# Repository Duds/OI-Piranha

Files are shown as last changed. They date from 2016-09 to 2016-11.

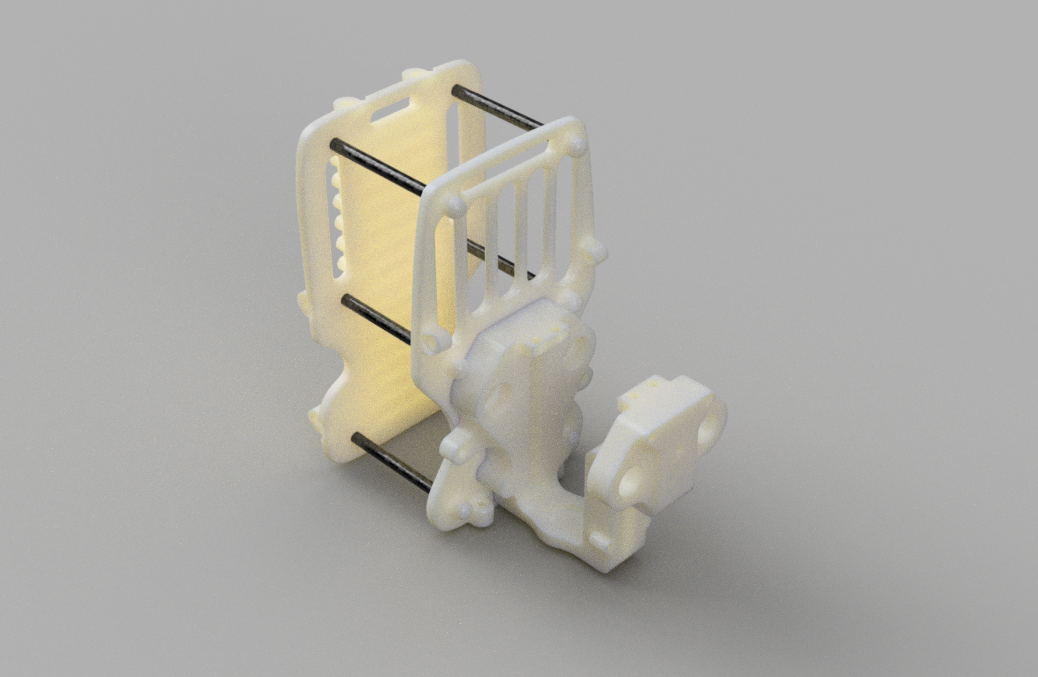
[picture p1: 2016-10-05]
200. Renders/Partial_Assembly_2016-Oct-04_11-32-55PM-000_CustomizedView4923803928.png

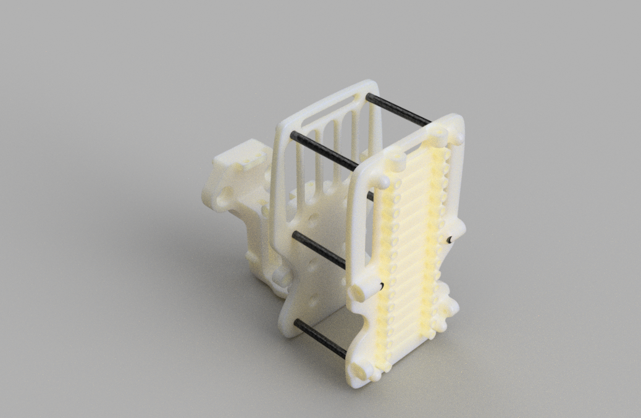
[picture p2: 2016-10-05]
200. Renders/Partial_Assembly_2016-Oct-04_11-32-44PM-000_CustomizedView13175151250.png

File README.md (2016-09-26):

# OI-Piranha
Open Inspired Piranha, an open source quadcopter design. Join the [Open Inspired community](http://openinspired.org) and get all the latest build tips, influence the design direction and start your own build log.

## Welcome to OI Piranha
I started OI Pirahna a bit by accident. I was trying to build the [DJI Inspired Version 1.5](http://www.rcgroups.com/forums/showthread.php?t=2399740) and the leadscrew I ordered arrived with a two start nut and a four start screw. I had some time to spare that I was planning to assemble my quad and so instead I sat down at my computer and wondered how hard it would be to design and print a four start nut for the leadscrew I had. As it happens 3d printing a four start nut won't work, the threads are too fine, for my printer anyway. So I designed a much larger leadscrew that would allow me to print a much larger nut. And then I thought this is silly, why am I copying a thread standard when I can design my own thread, with my own pitch and my own lead. Then, I thought hang on I don't even need a 360 degree continuos servo and top and bottom limit switches. All I need is a normal servo and I'll design the leadscrew to lift the body using the normal throw of the servo. Then I needed to know what the normal lift length was so I could design a leadscrew that would lift the body in 90 degrees. 

Many hours later, and I had roughly redesigned most of the aircraft frame. I had also viewed a stack of youtube videos on Fusion 360 design and learned a lot about top down design, the Fusion 360 timeline and a whole pile of stuff about 3d modelling.

When I was finished that first rough draft on my first night cram session I stood back and took a look at the frame and lift mechanism I had designed. I hadn't started on a fairing then. For some reason, the lump back where the battery goes and stubby little snout where the gimbal frame is reminded me of a fat stubby angry little predator fish. Not the lean fast fish like a tuna, but something maneuverable, still pretty fast, but much shorter and more agile. I went online to find out what kind of predator fish was short fat stubby and nasty. I found a photo of Piranha. I knew straight away that is what I had designed, a Piranha. And so I copied the photo of the pirahna in as a canvas and started work on my fairing.

## The Source
This design has been originally produced in Fusion 360. The original live source CAD file is at http://a360.co/2df5nqY

##Warning - Under Design
You are very welcome to make a fork of this design and to download the parts and print them. However, please be aware, this design is still a work in progress. Parts may not fit, or may break in use. Things may change and different versions of parts may not be compatible with versions of parts that you have printed. You might need to print things multiple times or find that parts fail during printing. All these challenges mean that, for now, the responsibility of starting and finishing an OI Piranha is not small. If you do take on the job your feedback is valued. Send your feedback good and bad to [Dale](mailto://hello@dalerogers.com.au)

##Credits
The Pirahna wouldn't exist if there weren't other DJI Inspired quadcopters before mine.
The first DJI Inspired was designed by [BlackBox RC](http://www.blackboxrc.co.uk/)
The BlackBox RC DJI Inspired was then modified, as the DJI Inspired v1.5 by Fragmaster on [RCGroups](http://www.rcgroups.com/forums/showthread.php?t=2399740)

Fragmaster was substantially supported during design by feedback and contributions from:
[Helifrek](http://www.rcgroups.com/forums/showthread.php?t=2330047),
[Mr.RCCAM](http://www.rc-cam.com/),
RTRyder,
[VladMiami](http://www.rcgroups.com/forums/showthread.php?t=2736573), and
many other contributors at [RCGroups](http://www.rcgroups.com/forums/showthread.php?t=2399740)

You can also find Thingiverse makes of the [BlackBox RC DJI Inspire](http://www.thingiverse.com/thing:593132) and, the [Fragmaster DJI Inspired V1.5](http://www.thingiverse.com/thing:909384)

I humbly apologise if you have contributed to the development of the DJI Inspired family of 3d printed quadcopters and you have not been mentioned. Please drop me an email at hello@dalerogers.com.au and I will correct the oversight. 

Those credited above have contributed to a great design, but all errors are mine.

Dale

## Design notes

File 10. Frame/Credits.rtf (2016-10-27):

These files were contributed by Whitedrag0n

Servo Caddy Top Mount.step
Servo Caddy Top Mount.iges
Servo Caddy Top Mount.stl

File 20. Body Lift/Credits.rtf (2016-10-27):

These files were contributed by Corwest

Lead Screw 9mm.step
Lead Screw 9mm.stl

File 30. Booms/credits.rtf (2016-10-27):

These files were contributed by Corwest

Boom Joint 16mm v1.1.step
Boom Joint 16mm v1.1.stl

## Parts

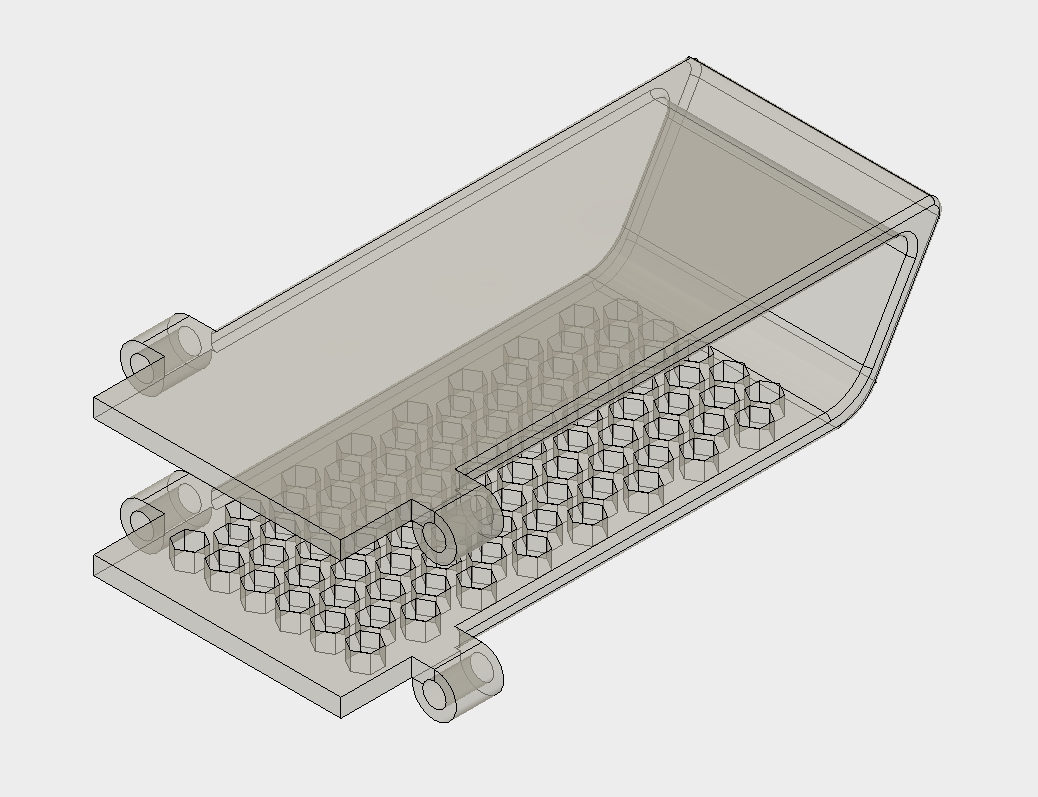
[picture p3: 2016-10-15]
40. Expansion Parts/DJI NAZA system expansion shelf.png

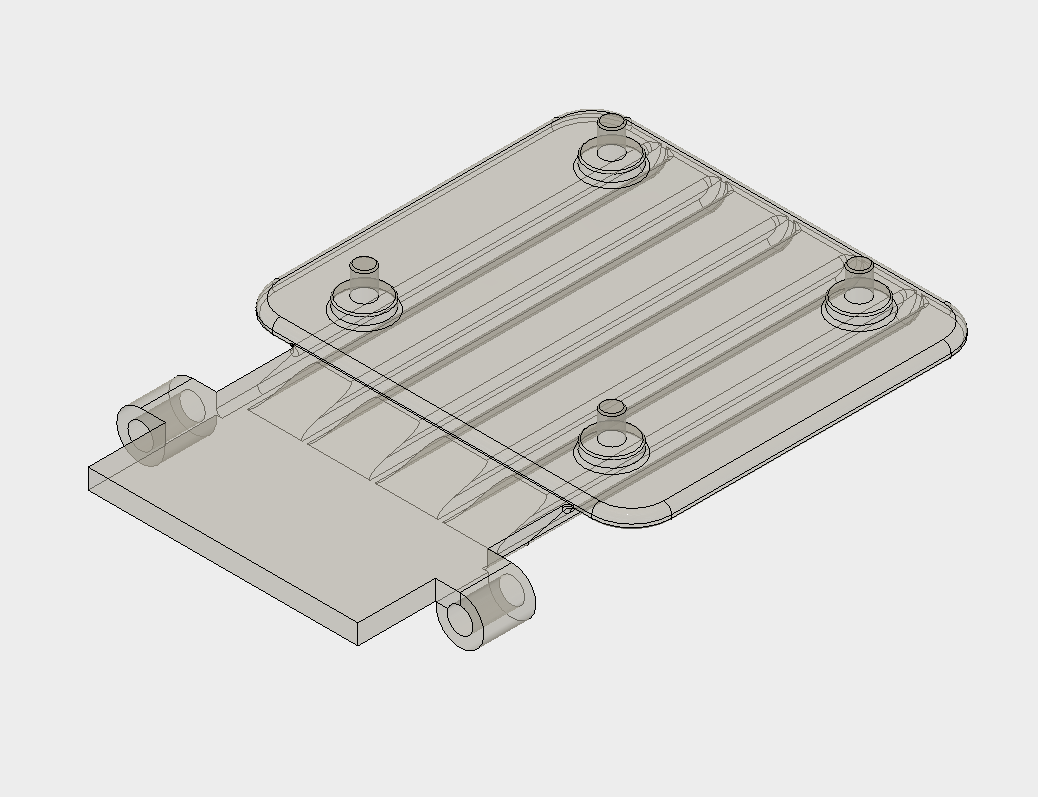
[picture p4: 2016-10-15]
40. Expansion Parts/NAZE32 expansion shelf.png

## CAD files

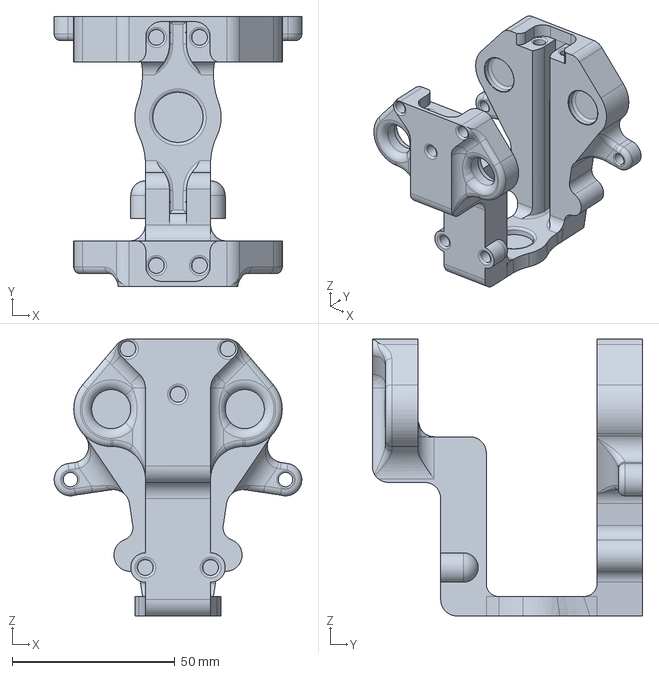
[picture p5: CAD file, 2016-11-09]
10. Frame/Main Frame.step
76.0 x 83.0 x 85.0 mm

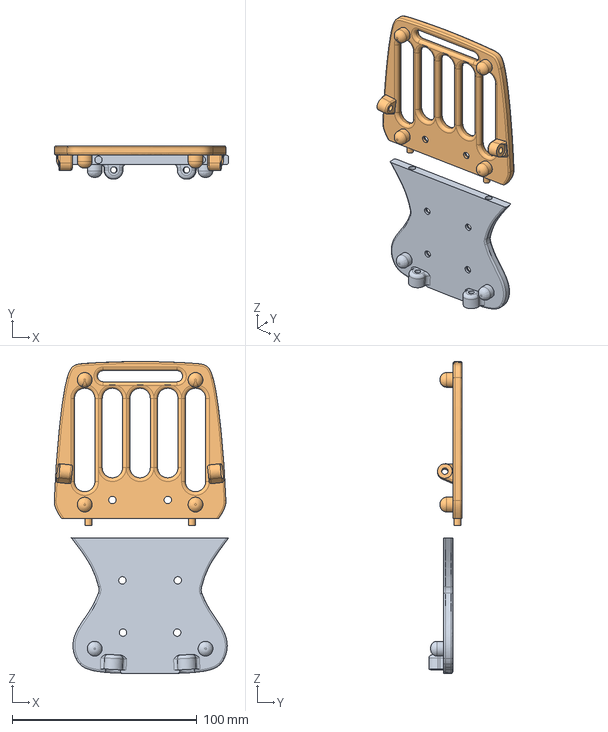
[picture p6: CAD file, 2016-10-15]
10. Frame/10.1 Two Part Frames (for smaller print volumes)/Battery Frame Two Part v1.step
94.5 x 18.1 x 168.9 mm
Battery Frame Part A
Battery Frame Part B

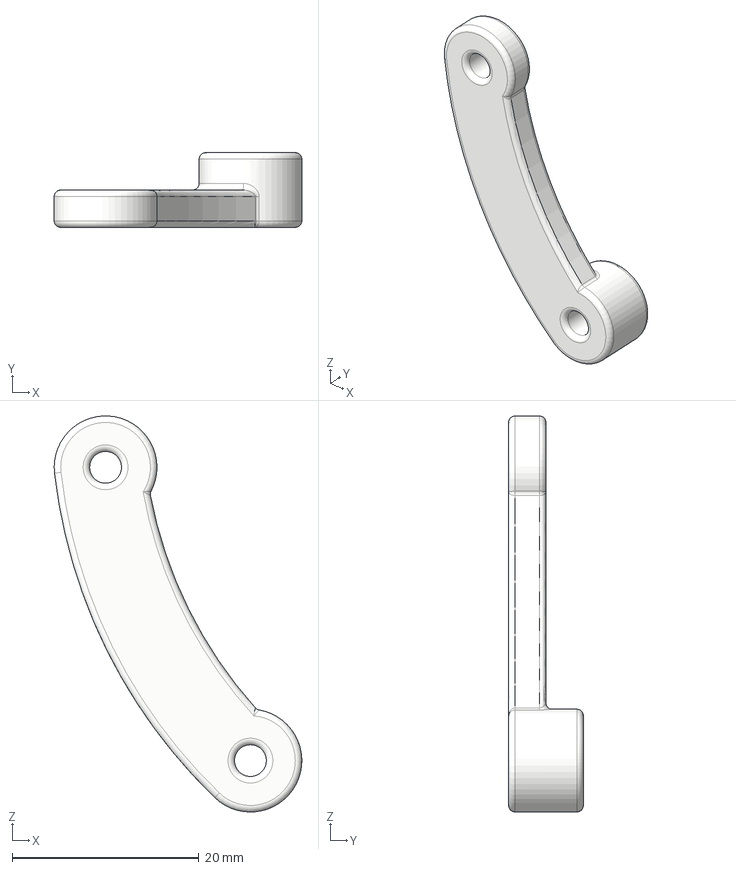
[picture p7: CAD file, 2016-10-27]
30. Booms/Lift linkage A.step
26.5 x 8.00 x 42.4 mm

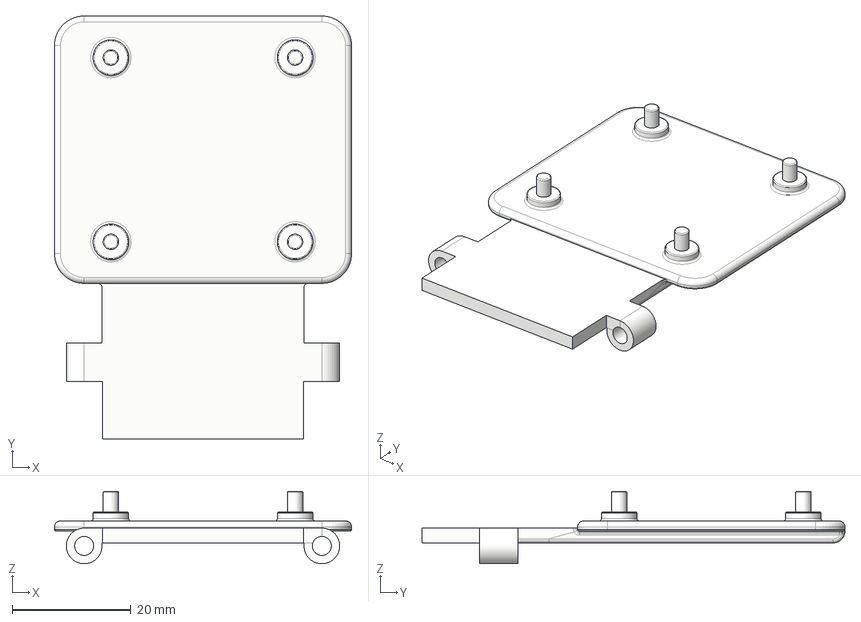
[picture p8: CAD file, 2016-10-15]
40. Expansion Parts/NAZE32 Expansion Shelf.step
50.0 x 71.2 x 12.2 mm

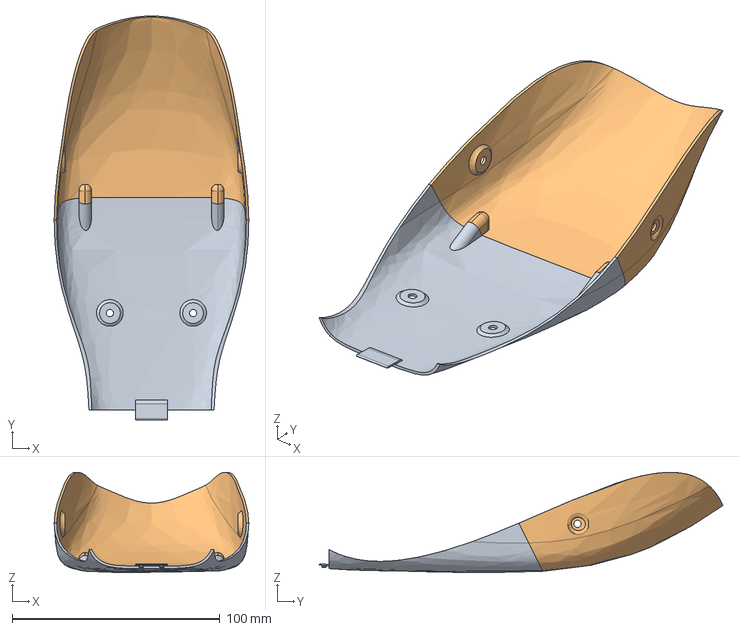
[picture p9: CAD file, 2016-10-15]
50. Fairings/50.1 two part fairing/Bash Plate Two Part.step
93.8 x 194.5 x 48.3 mm
Bash Plate part A
Bash Plate part B

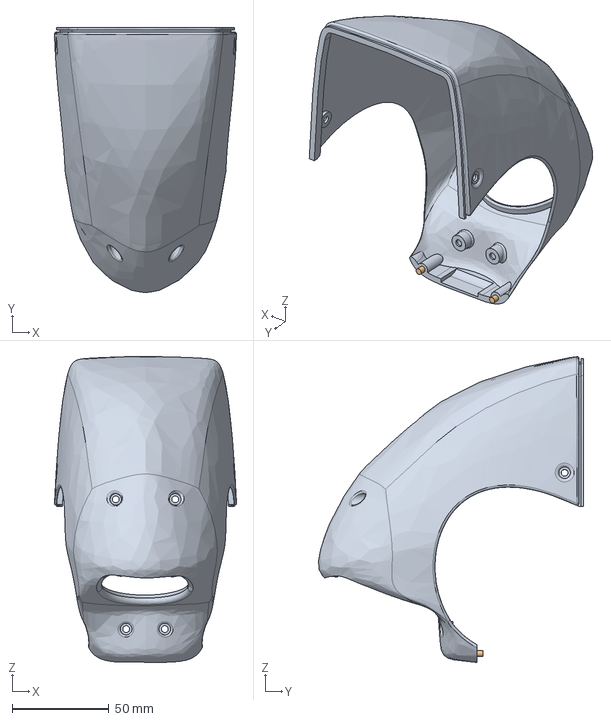
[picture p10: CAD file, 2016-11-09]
50. Fairings/Nose Fairing.step
94.2 x 137.1 x 158.3 mm

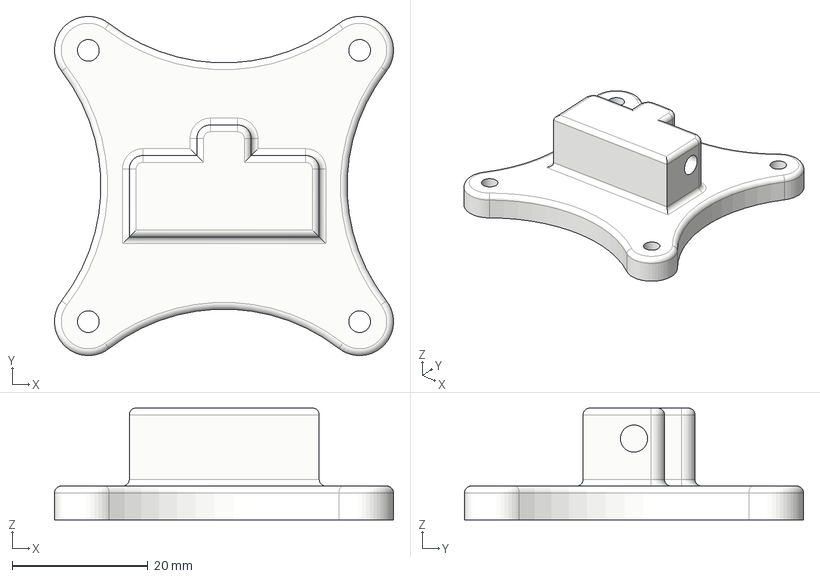
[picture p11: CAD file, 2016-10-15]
60. Payload/Gimbal Support.step
50.0 x 50.0 x 16.5 mm

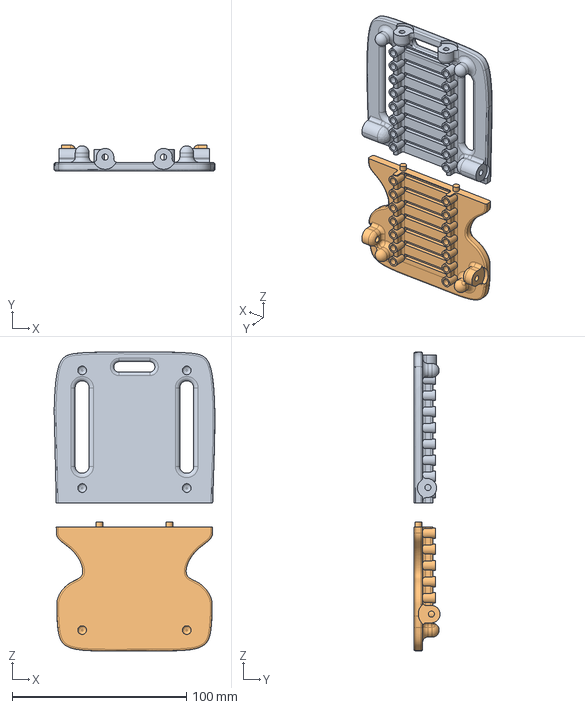
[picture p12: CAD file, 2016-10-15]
10. Frame/10.1 Two Part Frames (for smaller print volumes)/Expansion Frame Two Part.step
92.2 x 15.0 x 171.5 mm

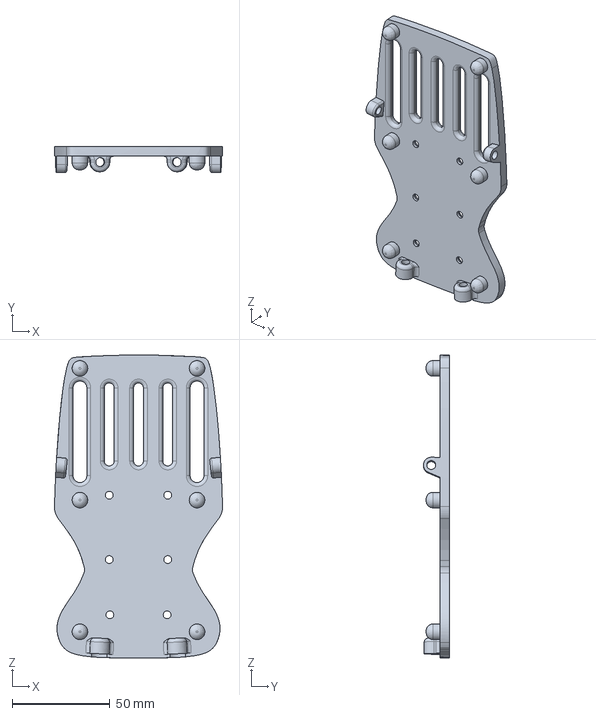
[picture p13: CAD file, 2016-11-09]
10. Frame/Battery Frame.step
86.2 x 13.4 x 155.3 mm

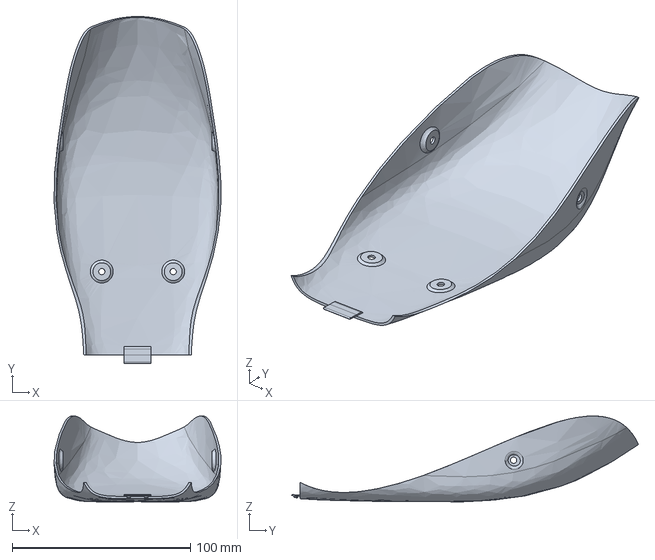
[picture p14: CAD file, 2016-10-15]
40. Expansion Parts/Bash Plate v12.step
93.6 x 194.5 x 48.2 mm

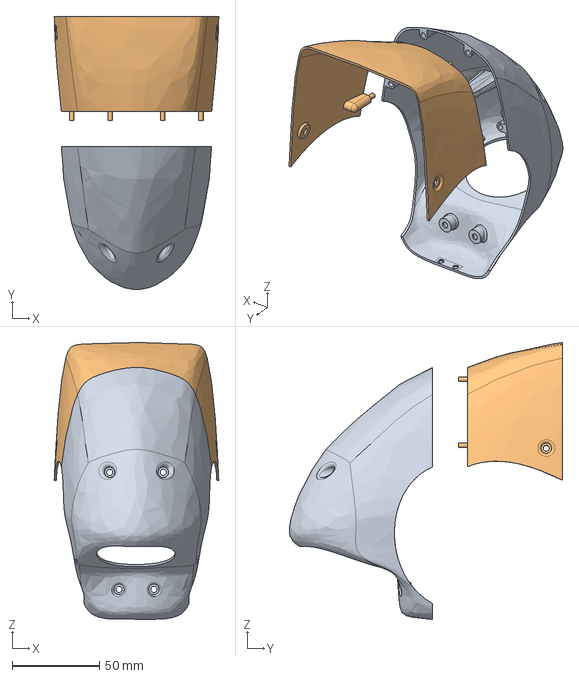
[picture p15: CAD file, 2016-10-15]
50. Fairings/50.1 two part fairing/Nose fairing two part.step
94.4 x 156.7 x 158.8 mm

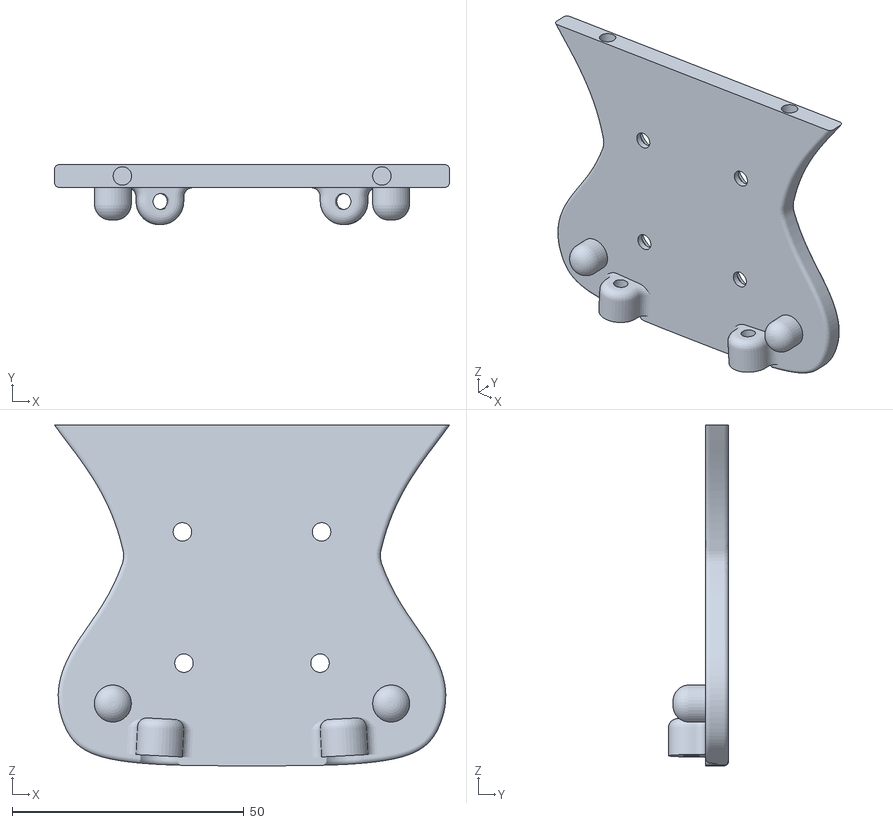
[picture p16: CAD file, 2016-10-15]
10. Frame/10.1 Two Part Frames (for smaller print volumes)/Battery Frame Part A.stl
85.1 x 13.0 x 73.4

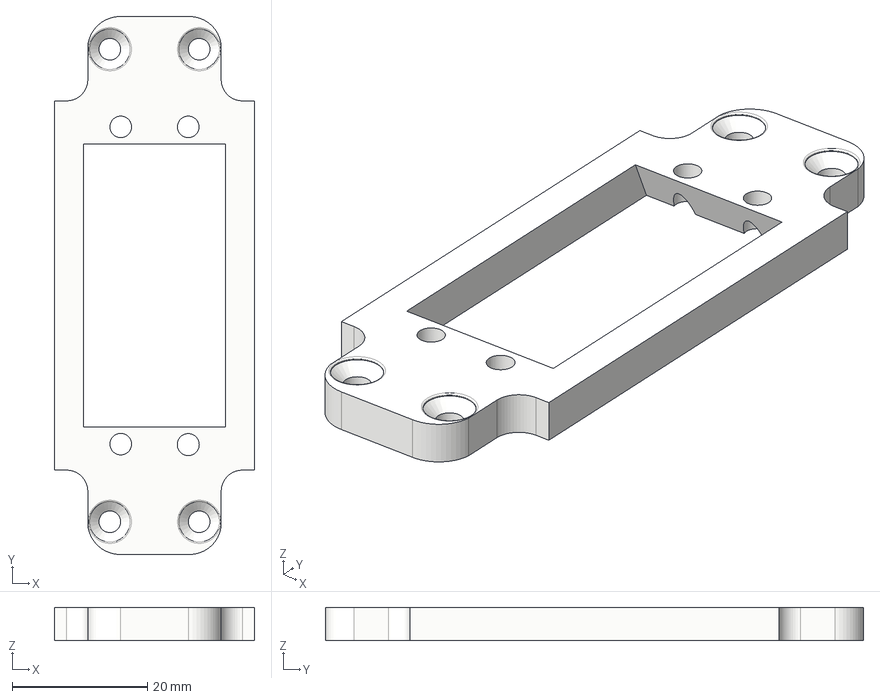
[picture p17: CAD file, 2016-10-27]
10. Frame/Servo Caddy.step
29.7 x 79.7 x 4.90 mm

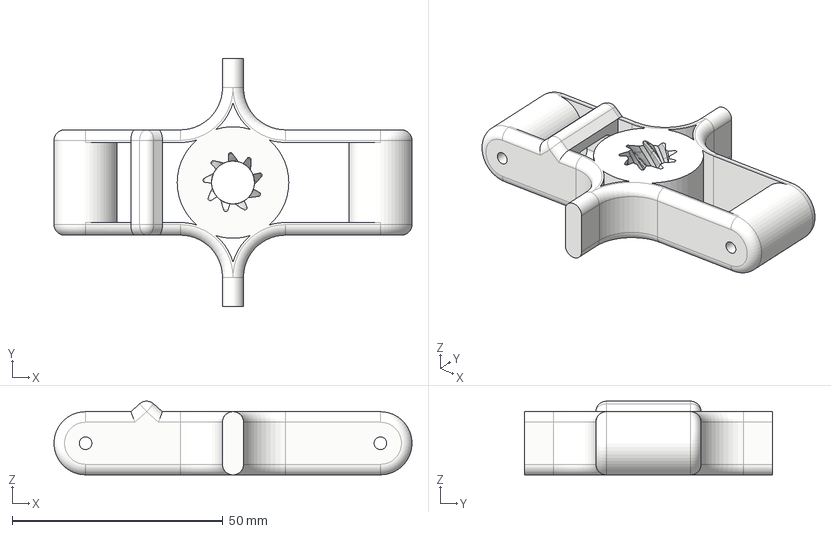
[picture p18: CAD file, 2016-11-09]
20. Body Lift/Lifting Beam (buttress thread).stp
85.0 x 58.8 x 17.5 mm

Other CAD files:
30. Booms/Lift Linkage B.step
50. Fairings/Bash Plate.step
30. Booms/Landing gear pivot.step
40. Expansion Parts/Basic Expansion Shelf.step
10. Frame/10.1 Two Part Frames (for smaller print volumes)/Battery Frame Part B.stl
10. Frame/10.1 Two Part Frames (for smaller print volumes)/Battery Frame Two Part v1.iges
10. Frame/10.1 Two Part Frames (for smaller print volumes)/Expansion Frame Two Part A.stl
10. Frame/10.1 Two Part Frames (for smaller print volumes)/Expansion Frame Two Part B.stl
10. Frame/10.1 Two Part Frames (for smaller print volumes)/Expansion Frame Two Part.iges
10. Frame/10.1 Two Part Frames (for smaller print volumes)/Lifting beam.step
10. Frame/Battery frame.iges
10. Frame/Battery frame.igs
10. Frame/Battery frame.stl
10. Frame/Expansion Frame.igs
10. Frame/Expansion Frame.step
10. Frame/Expansion frame.stl
10. Frame/Gimbal Support Frame.step
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

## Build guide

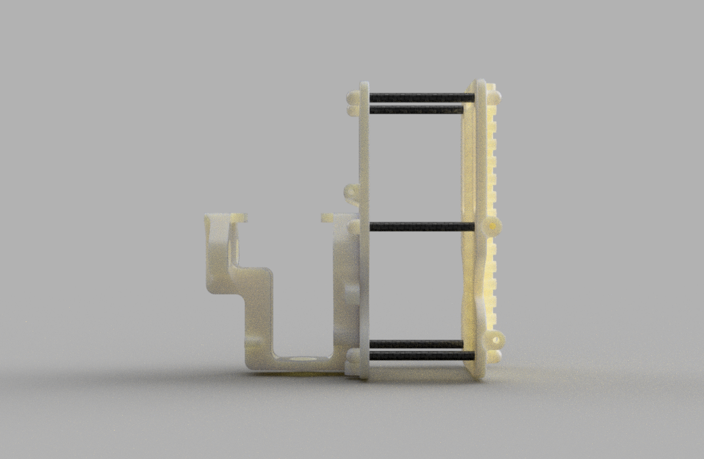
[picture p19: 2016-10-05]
200. Renders/Partial_Assembly_2016-Oct-04_11-33-06PM-000_CustomizedView22012456140.png

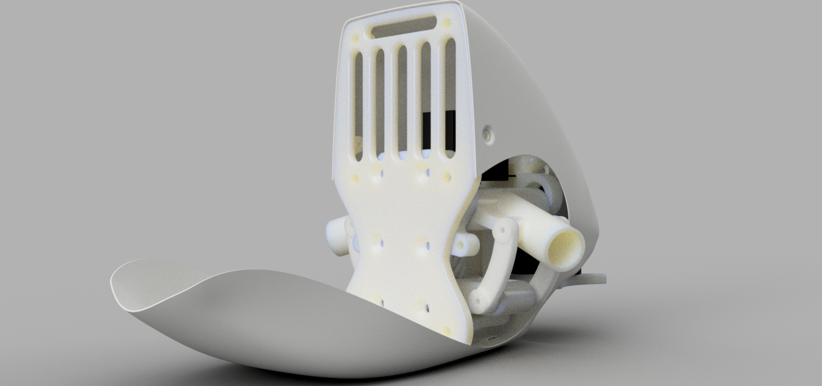
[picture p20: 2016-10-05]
200. Renders/Partial_Assembly_2016-Oct-01_11-00-10AM-000_CustomizedView1143942882.png

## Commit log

2016-09-24 Added first published .stl files
    Published the first copies of .STL files for printing
    Published renders of parts to be printed
    [Basic expansion shelf.stl, Battery Frame.stl, Boom joint left.stl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]
2016-09-26 Frame and Lift Mechanism Ready for Print
    1. The Frame, Body Lift and Payload are ready for printing test parts.
    They are 99% done and may only need some minor tweaking if test parts
    don’t fit nice.
    2. A folder structure has been established that will permit part group
    numbers. 10 is Frame parts, 20 is Body Lift parts 40 is Expansion parts
    and 60 is Payload parts. Folders prepended with / are not ready for
    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
    [Basic Expansion Shelf.iges, Basic Expansion Shelf.stl, Basic expansion shelf.stl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]
2016-09-26 Minor commit correction
    Booms folder should have been ignored by commit. Corrected previous
    commit so booms folder is ignored.
    [Boom joint left.stl, Boom joint right.stl, Lift linkage A.stl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]
2016-10-01 Fitting the nose fairing
    Fitted the nose fairing to the frame and added screw nodes.
    Fitted the bash plate to the frame and added screw nodes.
    Changed shape of battery frame slightly to fit the fairing better.
    Cleaned up fillets on frame.
    [Bash Plate.iges, Bash Plate.stl, Battery frame.iges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]
2016-10-05 Frame and fairing ready for print
    First release final frame and fairing.
    Ready for printing.
    [Bash Plate.iges, Bash Plate.stl, Bash plate.igs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]
2016-10-05 Added two part nose fairing
    Feedback from Whitedrag0n that parts won’t fit on smaller printer beds.
    Amended nose fairing to be two part and added locator pins.
    [Two part nose fairing part no 1.stl, Two part nose fairing part no 2.stl]
2016-10-08 Add Boom Joint and minor update to Main Frame
    The big change this update is the boom joint.
    The boom joints have a cable duct that direct wiring out the front
    pivot points. I have also removed the requirement for a boom pivot
    shaft and replaced with compression node pivots. The boom joint will
    squeeze into the frame with a click.
    I have also made minor adjustments to fit on the main frame. The bottom
    leadscrew seat has been thickened by 1mm.
    [Boom joint left.stl, Boom joint right.stl, Landing gear pivot.iges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]
2016-10-08 Minor change to length of lift rod connector
    Minor change to length of lift rod connector. Adjusted length of lift
    rod connector boss to correct length to fit lifting beam.
    [Landing gear pivot.iges, Landing gear pivot.stl]
2016-10-11 Small volume printer parts
    This commit updates the following:
    ## Frame
    Added two part battery frame for small volume printers
    Added two part expansion frame for small volume printers
    Updated main frame to better fit new click-in landing gear pivot and
    added large radius fillet to forward pivot point on frame to allow
    smooth cable exit.
    ## Other parts
    Shortened lead screw 3mm to fit aerostar servos
    Increased internal diameter of landing gear pivot carbon fibre tube
    entry to 18.2mm for better fitting carbon fibre tube install.
    Removed 1mm boss on landing gear lift linkage for easier printing, so
    the linkage would have a flat surface on the print bed.
    ## Fairings
    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
    [Bash Plate.iges, Bash Plate.stl, Bash plate.igs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]
2016-10-15 .step files added by request
    Added .step files by request @corwest and @stanv
    Added two part bash plate by request @whitedrag0n
    Modified main frame after feedback from @whitedrag0n and @StanV
    regarding easier assembly option by adding servo caddy
    Added servo Caddy after feedback from @whitedrag0n and StanV regarding
    easier assembly option
    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
    [Bash Plate Two Part.iges, Bash Plate Two Part.step, Bash Plate part A.stl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]
2016-10-15 Added png of assembled caddy and servo
    Added png of assembled caddy and servo
2016-10-21 Boom Joints Exact 16mm
    Boom joints with exact 16mm openings for printing with filament that has
    no shrinkage. Added top, bottom, and aft wire routing holes. Added back
    holes for srews that I left out in V1
    [Boom Joint 16mm V1.1.step]
2016-10-22 9.5mm Extended lead screw
    Extended the collar by 9.5mm to accept the servo beiong mounted topside
    of the caddy. Also narrowed the servo sleeve by .25mm to have a nice
    snug fit on the servow gear.
    [Lead Screw 9mm.step]
2016-10-22 Changes to accomodate more servos
    Original Design only allowed for 20mm by 38mm servos
    Width increased to 22mm
    Length increased to 41mm
    Cut-outs added to allow for flush mounting of servo from top
    [Servo Caddy.iges, Servo Caddy.step, Servo Caddy.stl]
2016-10-27 Lift body assembly
    This commit introduces changes based on the lift body assembly. Actual
    assembly of the lift body identified:
    lift beam guide too small
    caddy mount holes too small
    lift linkage holes too small
    lift pivot linkage holes too small
    All these issues are fixed by this commit.
    Also modified whitedrag0n’s caddy to better fit his servo
    [Landing gear pivot.iges, Landing gear pivot.step, Landing gear pivot.stl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]
2016-11-09 Lead screw, fairings and main frame edits
    This commit adds:
    Minor edits to the main frame reducing the width between the lifting
    beam guides
    Adding pin guides in the main frame lifting beam guides
    Adding a buttress thread leadscrew and associated nut die and lifting
    beam
    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
    [Bash Plate.iges, Bash Plate.step, Bash Plate.stl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]
